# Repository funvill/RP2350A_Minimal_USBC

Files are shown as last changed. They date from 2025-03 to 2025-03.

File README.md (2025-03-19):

# RP2350A Minimal Board KICad with USBC LCSC/JLCPCB parts

The primary goal of this project is to have a reference design for RP2350A, that uses USBC and has the LCSC/JLCPCB parts defined.

A secondary goal is to make the design physically small as possiable with one side SMD assembly.

**DO NOT USE** - This design has not been tested yet.

## Parts

- Microcontroller - [RP2350A](https://jlcpcb.com/partdetail/RaspberryPi-RP2350A/C42411118) (C42411118)
- Polarised inductor [Abracon AOTA-B201610S3R3-101-T](https://jlcpcb.com/partdetail/AbraconLlc-AOTA_B201610S3R3_101T/C42411119) (C42411119)
- Crystal oscillator [12 MHz Abracon ABM8-272-T3](https://jlcpcb.com/partdetail/AbraconLlc-ABM8_272T3/C20625731) (C20625731)
- 4Mb Flash - [Winbond Elec W25Q32JVUUIQ](https://jlcpcb.com/partdetail/WinbondElec-W25Q32JVUUIQ/C2999380) (C2999380)
- USB TYPE-C - [SHOU HAN USB TYPE-C 16PIN 2MD](https://jlcpcb.com/partdetail/ShouHan-TYPE_C_16PIN_2MD_073/C2765186) (C2765186) * Extended
- 3.3v Voltage Regulators - [AMS1117-3.3](https://jlcpcb.com/partdetail/Advanced_MonolithicSystems-AMS1117_33/C6186) (C6186)

## Design

The base design files came from [https://datasheets.raspberrypi.com/rp2350/Minimal-KiCAD.zip](https://datasheets.raspberrypi.com/rp2350/Minimal-KiCAD.zip)

I am trying to copy the power supply design from the [EasyEDA reference design with USBC](https://oshwlab.com/lckfb-team/coloreasypicox)

So that I can use the JLCPCB cupon here [RP2350 now available to buy: a high-performance, secure microcontroller for your next project](https://www.raspberrypi.com/news/rp2350-now-available-to-buy-a-high-performance-secure-microcontroller-for-your-next-project/)

## Helpful Links

- [KiCanvas](https://kicanvas.org/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) - In browser view of the KiCad files.
- [Hardware Design With RP2350](https://datasheets.raspberrypi.com/rp2350/hardware-design-with-rp2350.pdf)
- [EasyEDA2Kicad](https://github.com/uPesy/easyeda2kicad.py) - Converts JLCPCB parts to KiCad files.

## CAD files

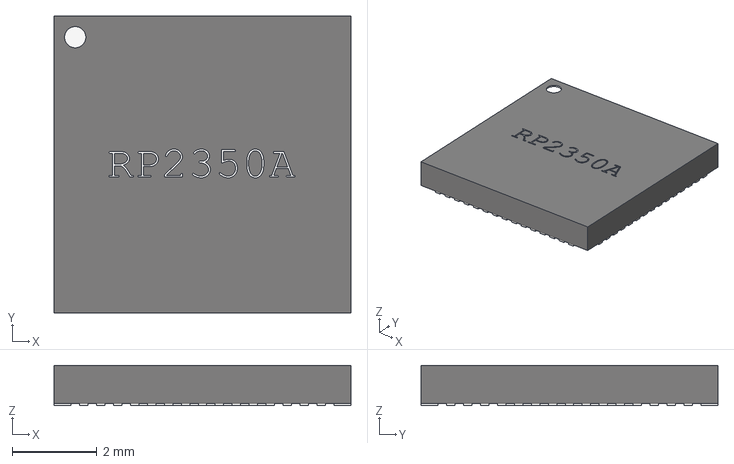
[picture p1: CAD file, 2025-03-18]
RP-006440-DD-2-RP2350A Minimal Board Kicad/RP2350_QFN60.step
7.00 x 7.00 x 0.95 mm

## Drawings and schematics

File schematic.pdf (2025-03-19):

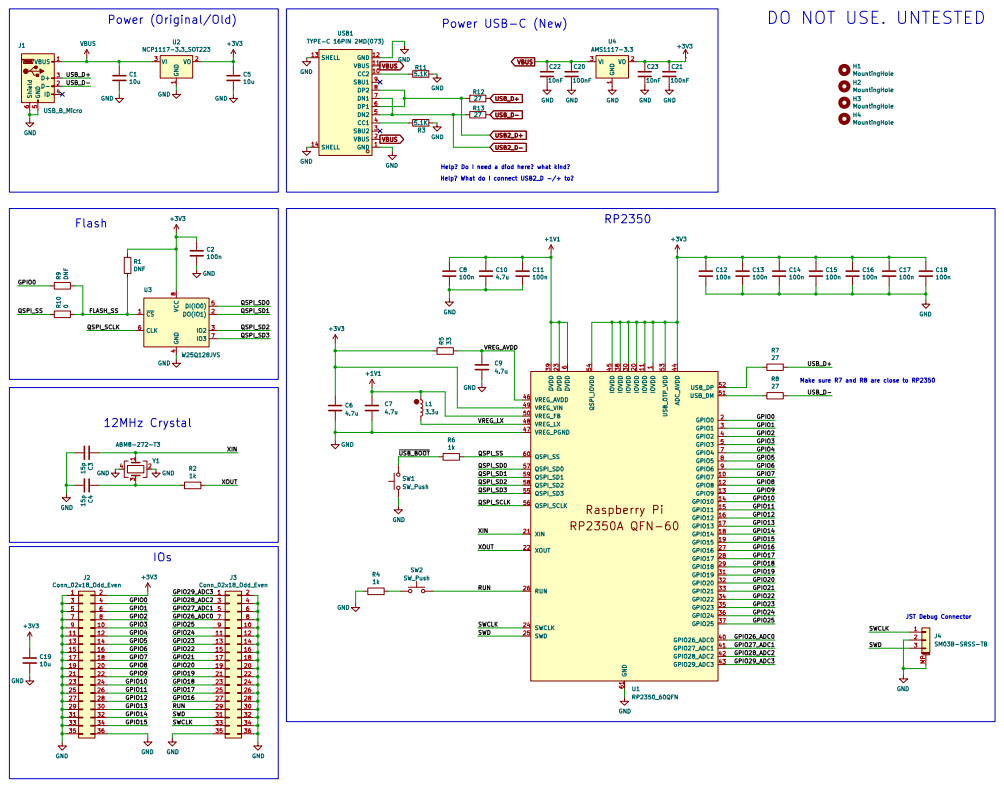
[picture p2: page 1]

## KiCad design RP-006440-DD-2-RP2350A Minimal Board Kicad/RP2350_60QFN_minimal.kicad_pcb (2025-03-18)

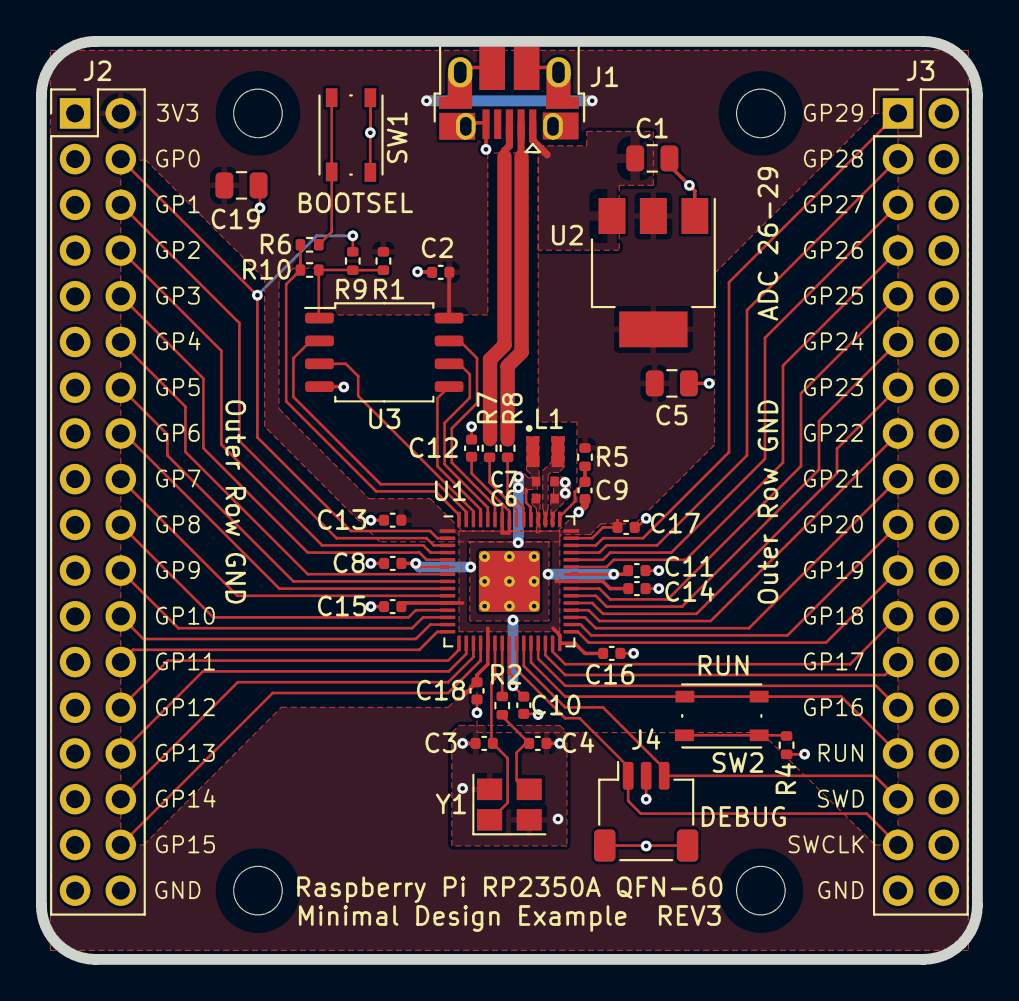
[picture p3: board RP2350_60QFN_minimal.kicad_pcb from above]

Board: 2 copper layers, 52.0 x 51.0 mm, 43 parts (0 on the bottom side), 55 nets.

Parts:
C1, C5, C19: 10u; C_0805_2012Metric
C2, C8, C11, C12, C13, C14, C15, C16, C17, C18: 100n; C_0402_1005Metric
C3, C4: 15p; C_0402_1005Metric
C6, C7: 4.7u; C_0402_1005Metric_small_pads
C9, C10: 4.7u; C_0402_1005Metric
H1, H2, H3, H4: MountingHole; MountingHole_2.7mm_M2.5
J1: USB_B_Micro; USB_Micro-B_Amphenol_10103594-0001LF_Horizontal
J2, J3: Conn_02x18_Odd_Even; PinHeader_2x18_P2.54mm_Vertical
J4: SM03B-SRSS-TB; JST_SH_SM03B-SRSS-TB_1x03-1MP_P1.00mm_Horizontal
L1: 3.3u; L_pol_2016
R1, R9: DNF; R_0402_1005Metric
R2, R4, R6: 1k; R_0402_1005Metric
R5: 33; R_0402_1005Metric
R7, R8: 27; R_0402_1005Metric
R10: 0; R_0402_1005Metric
SW1, SW2: SW_Push; SW_Push_1P1T_NO_Vertical_Wuerth_434133025816
U1: RP2350_60QFN; RP2350-QFN-60-1EP_7x7_P0.4mm_EP3.4x3.4mm_ThermalVias
U2: NCP1117-3.3_SOT223; SOT-223-3_TabPin2
U3: W25Q128JVS; SOIC-8_5.23x5.23mm_P1.27mm
Y1: ABM8-272-T3; Crystal_SMD_3225-4Pin_3.2x2.5mm

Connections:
+1V1: C7.1, C8.1, C10.1, C11.1, L1.1, U1.6 (DVDD), U1.23 (DVDD), U1.39 (DVDD), U1.50 (VREG_FB)
+3V3: C2.1, C5.1, C6.1, C12.1, C13.1, C14.1, C15.1, C16.1, C17.1, C18.1, C19.1, J2.2, R1.1, R5.1, U1.1 (IOVDD), U1.11 (IOVDD), U1.20 (IOVDD), U1.30 (IOVDD), U1.38 (IOVDD), U1.44 (ADC_AVDD), U1.45 (IOVDD), U1.49 (VREG_VIN), U1.53 (USB_OTP_VDD), U1.54 (QSPI_IOVDD), U2.2 (VO), U3.8 (VCC)
/FLASH_SS: R1.2, R9.2, R10.2, U3.1 (~CS)
/GPIO0: J2.4, R9.1, U1.2 (GPIO0)
/GPIO1: J2.6, U1.3 (GPIO1)
/GPIO2: J2.8, U1.4 (GPIO2)
/GPIO3: J2.10, U1.5 (GPIO3)
/GPIO4: J2.12, U1.7 (GPIO4)
/GPIO5: J2.14, U1.8 (GPIO5)
/GPIO6: J2.16, U1.9 (GPIO6)
/GPIO7: J2.18, U1.10 (GPIO7)
/GPIO8: J2.20, U1.12 (GPIO8)
/GPIO9: J2.22, U1.13 (GPIO9)
/GPIO10: J2.24, U1.14 (GPIO10)
/GPIO11: J2.26, U1.15 (GPIO11)
/GPIO12: J2.28, U1.16 (GPIO12)
/GPIO13: J2.30, U1.17 (GPIO13)
/GPIO14: J2.32, U1.18 (GPIO14)
/GPIO15: J2.34, U1.19 (GPIO15)
/GPIO16: J3.27, U1.27 (GPIO16)
/GPIO17: J3.25, U1.28 (GPIO17)
/GPIO18: J3.23, U1.29 (GPIO18)
/GPIO19: J3.21, U1.31 (GPIO19)
/GPIO20: J3.19, U1.32 (GPIO20)
/GPIO21: J3.17, U1.33 (GPIO21)
/GPIO22: J3.15, U1.34 (GPIO22)
/GPIO23: J3.13, U1.35 (GPIO23)
/GPIO24: J3.11, U1.36 (GPIO24)
/GPIO25: J3.9, U1.37 (GPIO25)
/GPIO26_ADC0: J3.7, U1.40 (GPIO26_ADC0)
/GPIO27_ADC1: J3.5, U1.41 (GPIO27_ADC1)
/GPIO28_ADC2: J3.3, U1.42 (GPIO28_ADC2)
/GPIO29_ADC3: J3.1, U1.43 (GPIO29_ADC3)
/QSPI_SCLK: U1.56 (QSPI_SCLK), U3.6 (CLK)
/QSPI_SD0: U1.57 (QSPI_SD0), U3.5 (DI(IO0))
/QSPI_SD1: U1.59 (QSPI_SD1), U3.2 (DO(IO1))
/QSPI_SD2: U1.58 (QSPI_SD2), U3.3 (IO2)
/QSPI_SD3: U1.55 (QSPI_SD3), U3.7 (IO3)
/QSPI_SS: R6.1, R10.1, U1.60 (QSPI_SS)
/RUN: J3.29, SW2.2, U1.26 (RUN)
/SWCLK: J3.33, J4.1, U1.24 (SWCLK)
/SWD: J3.31, J4.3, U1.25 (SWD)
/USB_D+: J1.3 (D+), R7.1
/USB_D-: J1.2 (D-), R8.1
/VREG_AVDD: C9.1, R5.2, U1.46 (VREG_AVDD)
/VREG_LX: L1.2, U1.48 (VREG_LX)
/XIN: C3.1, U1.21 (XIN), Y1.1
/XOUT: R2.1, U1.22 (XOUT)
/~USB_BOOT: R6.2, SW1.2
GND: C1.2, C2.2, C3.2, C4.2, C5.2, C6.2, C7.2, C8.2, C9.2, C10.2, C11.2, C12.2, C13.2, C14.2, C15.2, C16.2, C17.2, C18.2, C19.2, J1.5 (GND), J1.6 (Shield), J2.1, J2.3, J2.5, J2.7, J2.9, J2.11, J2.13, J2.15, J2.17, J2.19, J2.21, J2.23, J2.25, J2.27, J2.29, J2.31, J2.33, J2.35, J2.36, J3.2, J3.4, J3.6, J3.8, J3.10, J3.12, J3.14, J3.16, J3.18, J3.20, J3.22, J3.24, J3.26, J3.28, J3.30, J3.32, J3.34, J3.35, J3.36, J4.2, J4.MP (MountPin), R4.2, SW1.1, U1.47 (VREG_PGND), U1.61 (GND), U2.1 (GND), U3.4 (GND), Y1.2, Y1.4
unnamed: C4.1, R2.2, Y1.3
unnamed: R4.1, SW2.1
unnamed: R8.2, U1.51 (USB_DM)
unnamed: R7.2, U1.52 (USB_DP)
VBUS: C1.1, J1.1 (VBUS), U2.3 (VI)

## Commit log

2025-03-18 Updated readme and some of the JLCPCB parts
    [RP2350_60QFN_minimal.kicad_pcb, RP2350_60QFN_minimal.kicad_sch, RP2350_QFN60.step]
2025-03-19 Updated with USB-C circuit for review
    [RP2350_60QFN_minimal.kicad_pcb, RP2350_60QFN_minimal.kicad_sch, RP2350_QFN60.step]
